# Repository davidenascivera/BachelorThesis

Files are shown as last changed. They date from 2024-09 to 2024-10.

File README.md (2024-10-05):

# Infrared Signal Devices for Aerial Obstacles

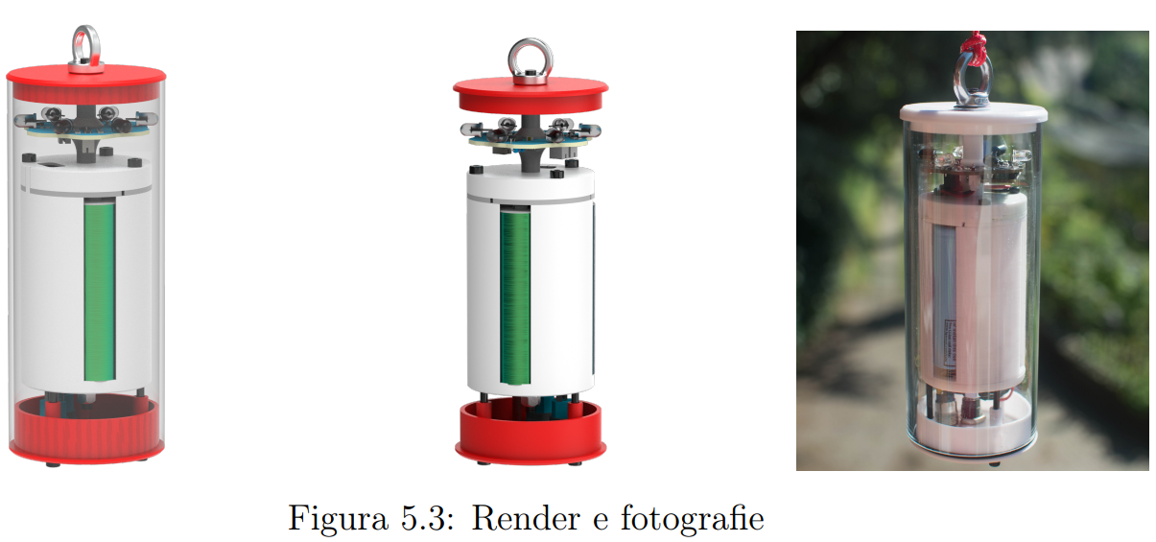
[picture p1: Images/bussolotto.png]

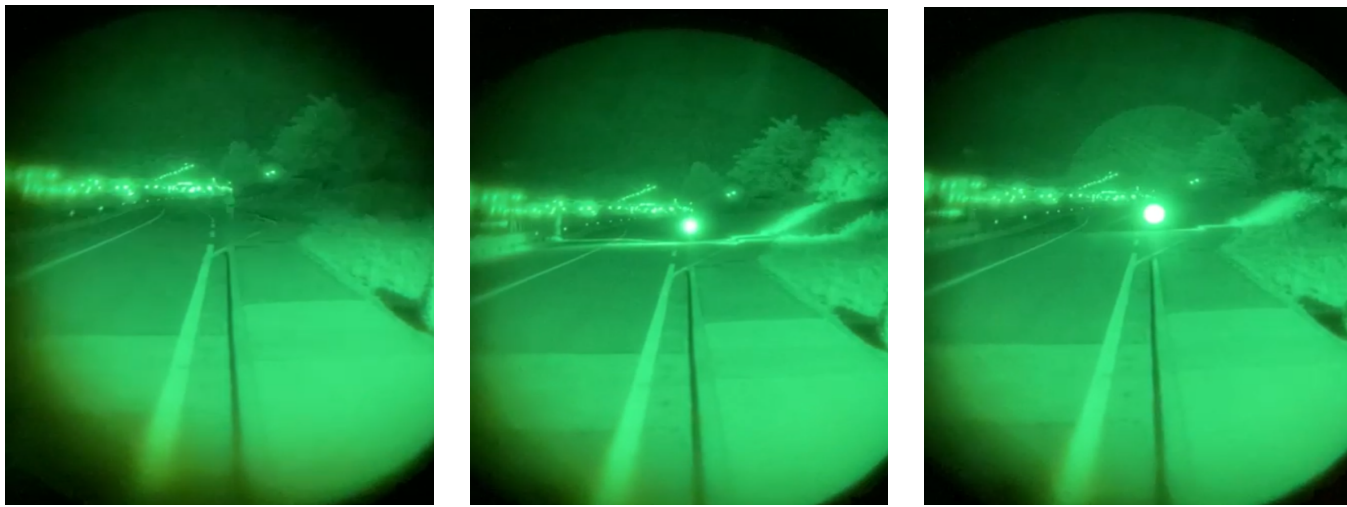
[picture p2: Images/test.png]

## Abstract

This project focuses on the design and development of **infrared signal devices** for aerial obstacle detection, aimed at improving the safety of temporary installations, such as **Highline** structures. Inspired by Swiss regulations for aerial navigation, these devices are designed to emit infrared light visible to night-vision equipment, particularly for helicopters used in rescue operations. The main goal is to offer an **open-source**, low-cost alternative to commercial infrared signal devices, which are often prohibitively expensive for nonprofit slackline communities.

## Project Overview

This repository contains the design files, schematics, and necessary documentation to build a fully operational infrared signal device, as developed in my Bachelor's thesis. The device has undergone several iterations, leading to the final version described below.

## Documentation

For more detailed information on the project, please refer to the following files:

- [Project Summary](Documentation/eng_summary.pdf)
- [Full_thesis](Documentation/eng_full_thesis)

Please note that the document was originally written in Italian and later translated for publication here.

### Features

- **Compact Design**: Comparable to a smartphone in size, the device is easy to transport and install.
- **Waterproof (IP67)**: The device is designed to operate in outdoor conditions, including rain.
- **Extended Battery Life**: With a single 18650 battery (3.2 Ah), the device can last up to 40 hours of continuous operation, or approximately 4 nights.
- **Cost-Effective**: The total cost per device is around €50, compared to €500 for commercial alternatives.
- **Customizable**: The device allows for various LED patterns and types, making it adaptable to different needs.

## Hardware Specifications

- **PCB Design**: The PCB was optimized for small-scale production, using **SMD components** to reduce size and improve performance.
- **LED Driver**: Infrared LEDs are powered by a dedicated current-driven LED driver, ensuring reliable operation and efficient power usage.
- **USB-C Charging**: The device includes a USB-C port for convenient recharging.
- **Visual Battery Indicator**: Upon powering on, the device shows the battery charge level via an LED, with 1 to 5 blinks indicating the charge status.

## Assembly Instructions

1. **Print the PCB Layout**: The design files for the PCB are included in the `/pcb_design` folder.
2. **Assemble Components**: Follow the schematic in the `/schematics` folder to solder the necessary components to the PCB.
3. **Install the Electronics in the Case**: The device case is designed for ease of access, with removable top and bottom covers for maintenance.
4. **Power On**: Once assembled, insert the battery, charge it via the USB-C port, and press the power button to activate the device.

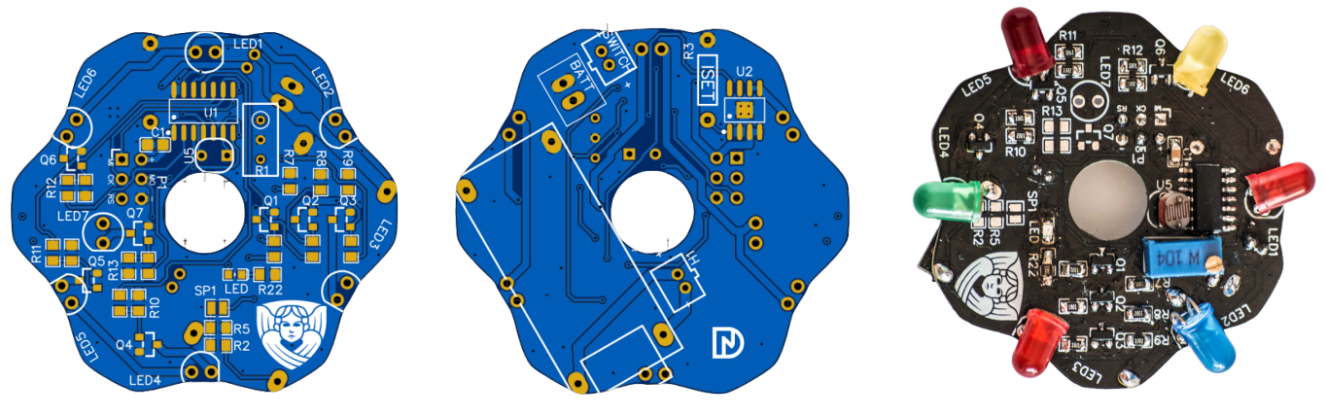
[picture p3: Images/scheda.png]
PCB of the system


## Testing and Validation

The device was tested in collaboration with the **Trento Helicopter Rescue Unit** to validate its performance. It was visible up to a distance of 500 meters under city light pollution and further in mountain environments, making it suitable for high-altitude slacklining installations.

## Future Improvements

- **Top-mounted Infrared LED**: Future versions could include an additional infrared LED visible from above.
- **Integrated Battery Management System (BMS)**: Incorporating the BMS directly into the PCB for a more seamless design.
- **Larger-Scale Production**: The current design is optimized for small-scale production, but further improvements can make it scalable for mass production.

## License

This project is open-source under the **MIT License**. Feel free to modify and adapt the design for your specific needs.
"""

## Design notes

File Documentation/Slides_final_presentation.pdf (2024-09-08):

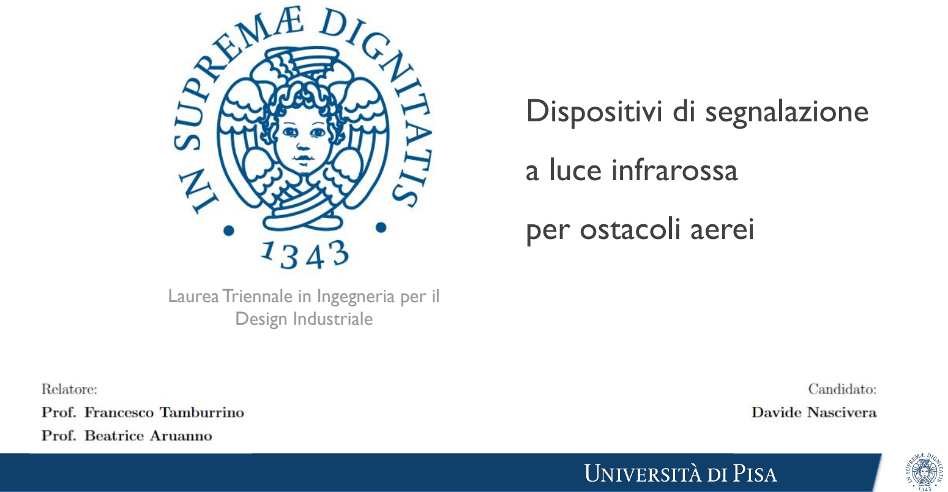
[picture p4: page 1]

## Dispositivi di segnalazione

## a luce infrarossa

## per ostacoli aerei

Laurea Triennale in Ingegneria per il Design Industriale

# Il problema

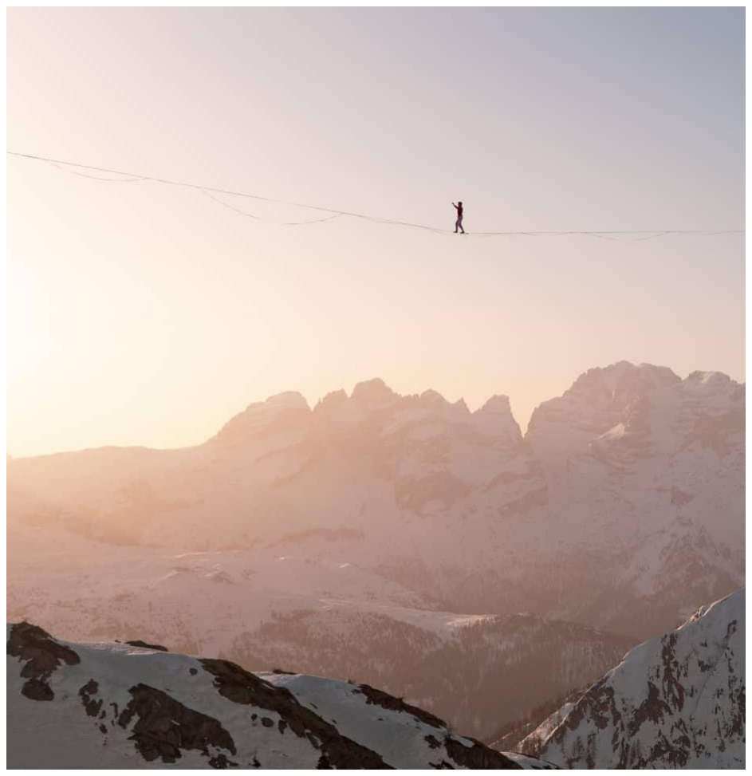
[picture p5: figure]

Lo Slacklining è lo sport, o disciplina, che consiste nel bilanciarsi e stare in equilibrio su una fettuccia tesa fra due punti di ancoraggio.

Fettucce sospese nel vuoto, quali Highline, rappresentano un rischio significativo per lo spazio aereo se non vengono gestite e controllate adeguatamente.
Pertanto durante le ore diurne vengono poste molteplici maniche a vento lungo un cordino parallelo alla linea, mentre di notte invece il problema persiste.

# Il problema

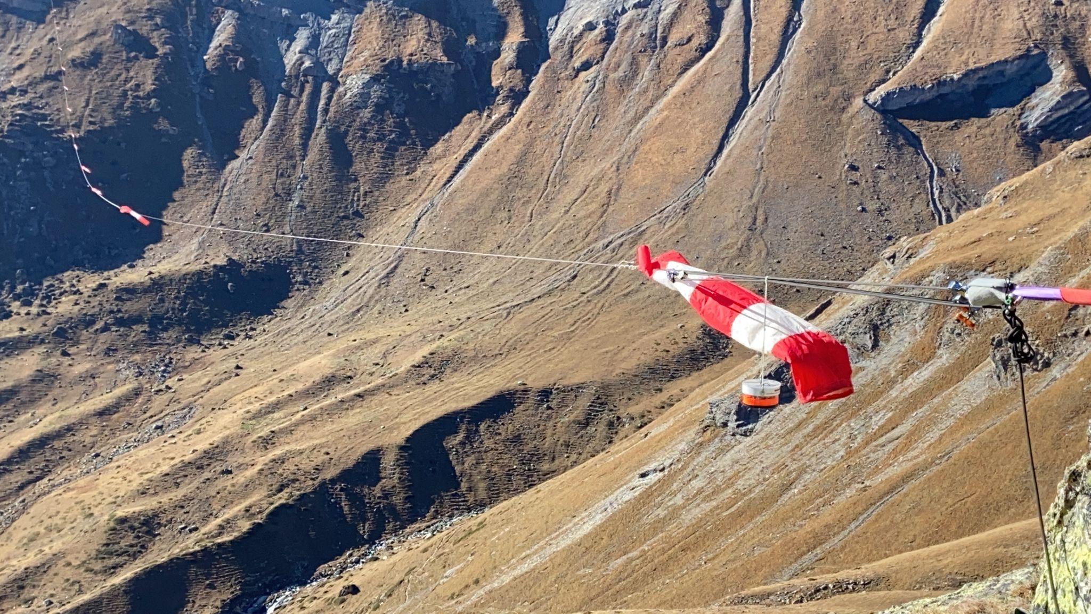
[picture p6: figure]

# Soluzione Svizzera:

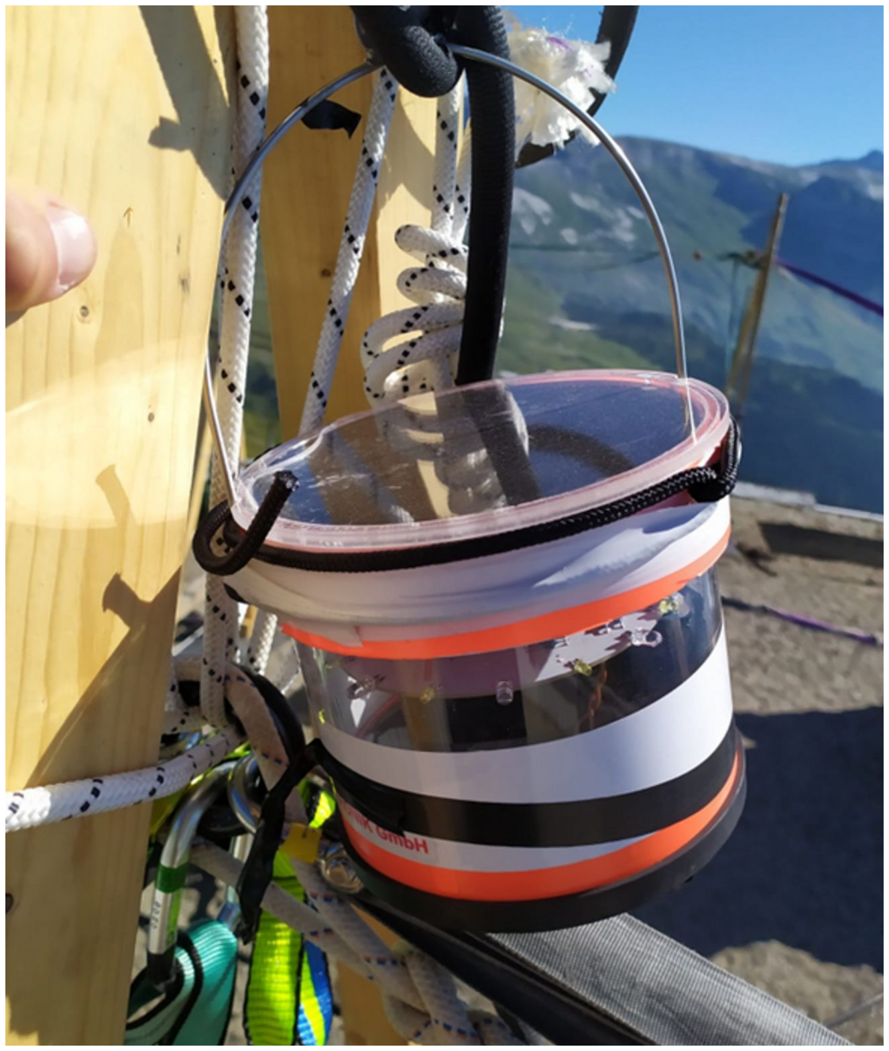
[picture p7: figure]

La Svizzera prevede già questo tipo d’installazione nella loro normativa locale.

I dispositivi di sicurezza usati dai cittadini costano 500 euro e il prezzo è proibitivo per associazioni no-profit dove non è obbligatorio l’utilizzo del dispositivo.

# Soluzione Open-Source:

L'obiettivo principale è lo sviluppo di un prodotto completo, accompagnato dalla pubblicazione di circuiti e file per la sua realizzazione, al fine di stabilire le basi per un sistema affidabile e conveniente.

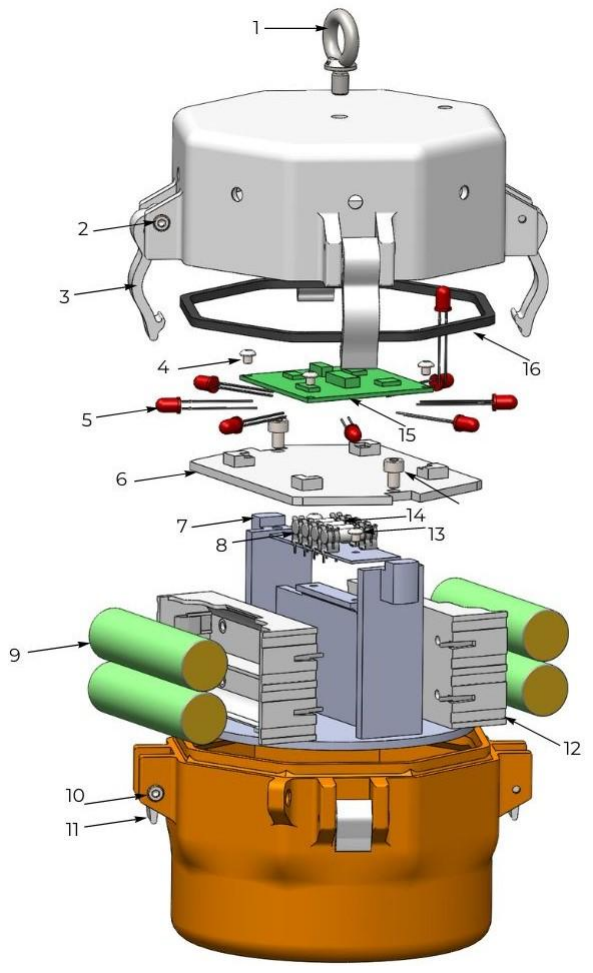
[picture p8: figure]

# Proof of concept

Sfruttando l’ispirazione derivante dal design dei dispositivi di segnalazione svizzeri, è stato possibile progettare e sviluppare un sistema di sicurezza basato su elementi già testati e affidabili, apportando però miglioramenti.

Il sistema si compone di una scocca esteriore impermeabile stampata in PETG che racchiude la parte elettronica e il pacco batterie al proprio interno.

8 LED infrarossi posizionati lungo i bordi dell'ottagono si attivano in modalità intermittente per fornire la segnalazione necessaria

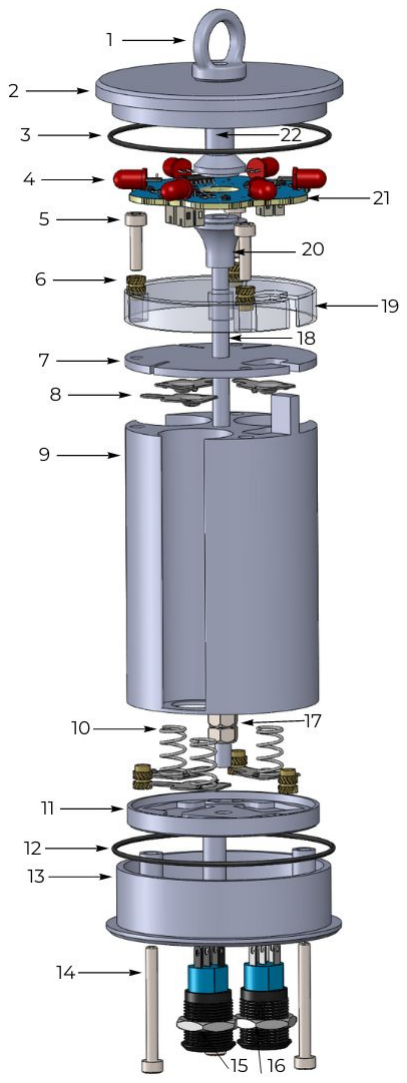
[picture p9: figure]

# Proof of work

La quarta e ultima versione del dispositivo risulta essere più elegante e avanzata a livello tecnico e meccanico.

Il risultato è un dispositivo con dimensioni paragonabili a quelle di uno smartphone, impermeabile e con un'elettronica efficiente che permette la messa in opera del dispositivo per 4 giorni per ogni batteria inserita.

Per ricaricare le batterie del dispositivo è sufficiente collegare la dedicata USB-C. Inoltre non è più necessario aprire il dispositivo per attivarlo, disponendo del pulsante d’accensione esterno.

Al momento dell'accensione, il dispositivo indica la percentuale di carica mediante il lampeggio di un LED integrato da 1 a 5 volte.

# Confronto fra dispositivi

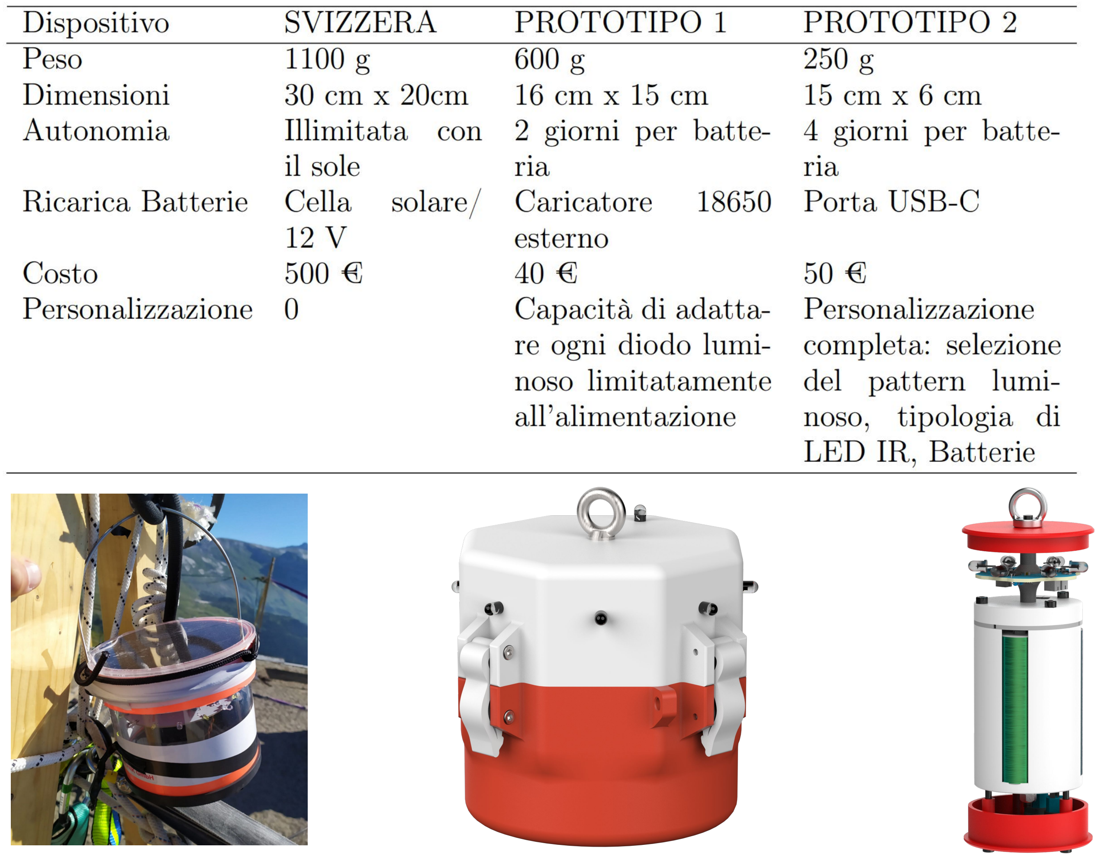
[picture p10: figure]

# Verifica del dispositivo

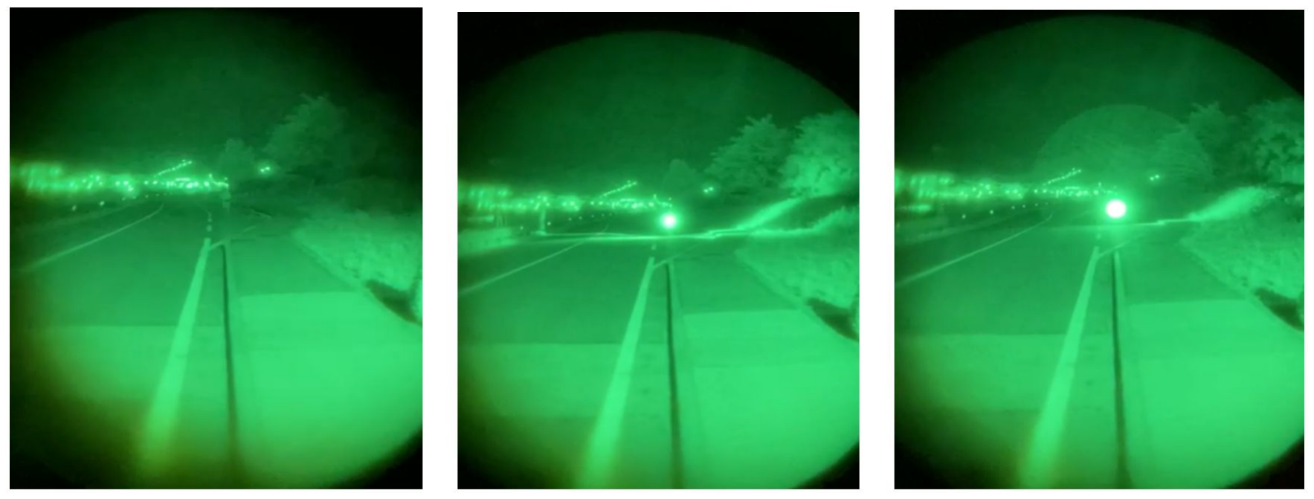
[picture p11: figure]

La validazione operativa è stata eseguita in collaborazione con il nucleo elisoccorso di Trento.
Il dispositivo risulta essere notevolmente visibile anche a una distanza di 500 m con l’inquinamento luminoso della città in prossimità dell’aeroporto.

In base alle numerose prove di laboratorio, il dispositivo è classificato con un grado di impermeabilità IP67 e offre la batteria offre un'autonomia di circa 12 giorni.

# Future implementazioni

Nonostante il progetto sia un prodotto completo e utilizzabile, esistono alcuni punti che potrebbero essere ampliati e perfezionati:

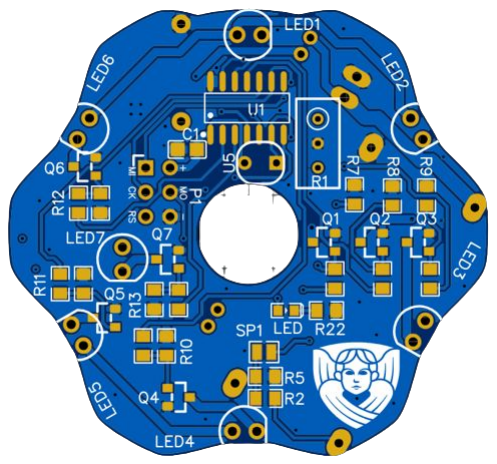
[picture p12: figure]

- Certificare il funzionamento del dispositivo, sia a livello elettronico che ottico da laboratori specifici.
- Implementazione del LED infrarossi superiore
- Inclusione del modulo di ricarica e del BMS all’interno della scheda elettronica

# Conclusioni

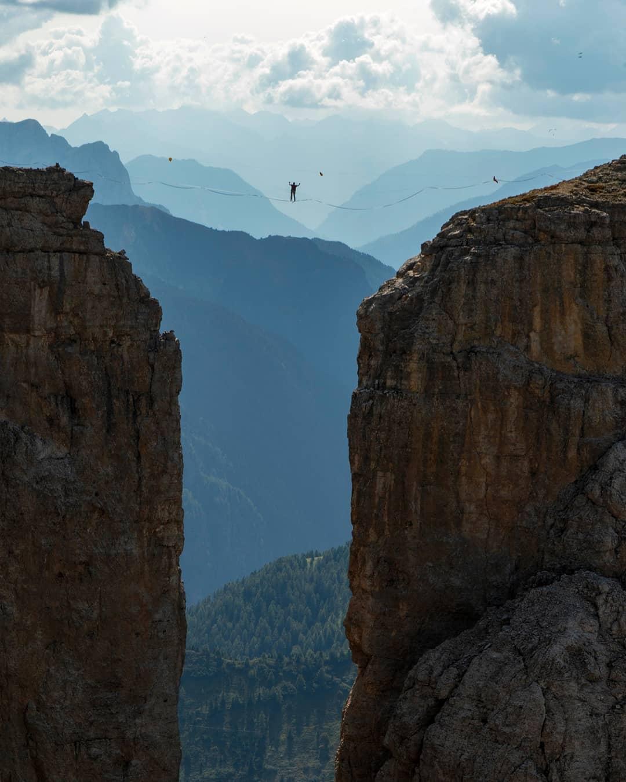
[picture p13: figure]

In conclusione si può affermare che è stato sviluppato un dispositivo in grado di affrontare con successo le sfide specifiche, caratterizzato da un design leggero, compatto e altamente portatile.

Il suo prezzo accessibile ed estremamente conveniente risulta particolarmente adatto per le comunità no-profit interessate alla slackline.

# Grazie per l’attenzione

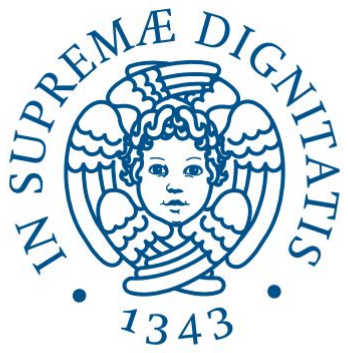
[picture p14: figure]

# Domande:

# Montaggio di un’Highline

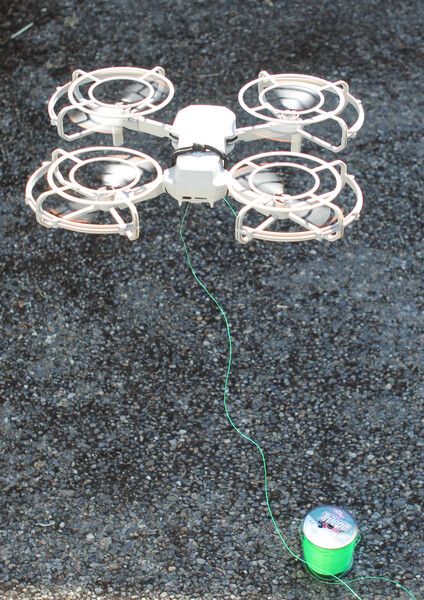
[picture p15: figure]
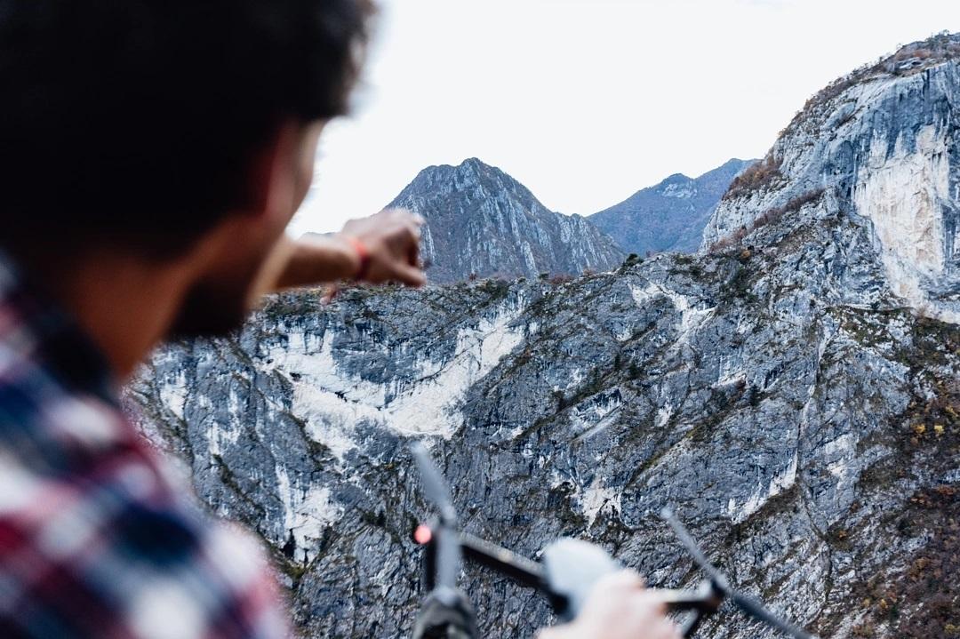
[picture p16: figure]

1. Ricerca della location. | 2. Utilizzo del drone per
| passaggio della bava.

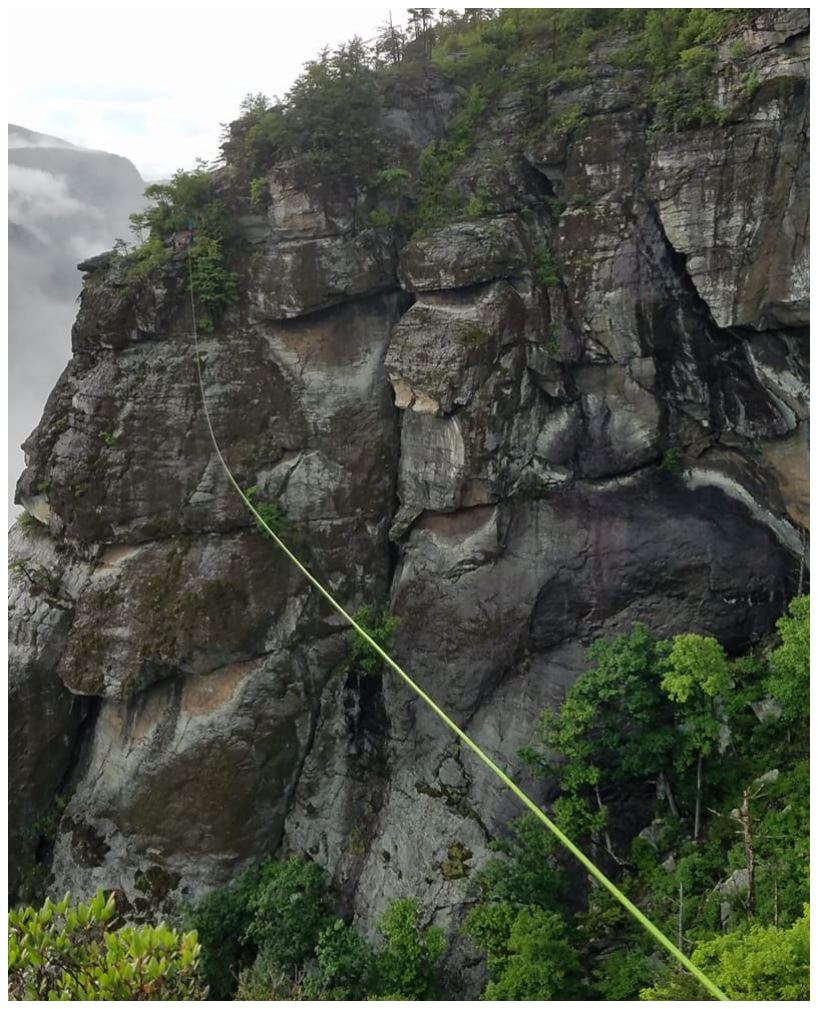
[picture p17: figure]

3. Passaggio della
tagline con la bava

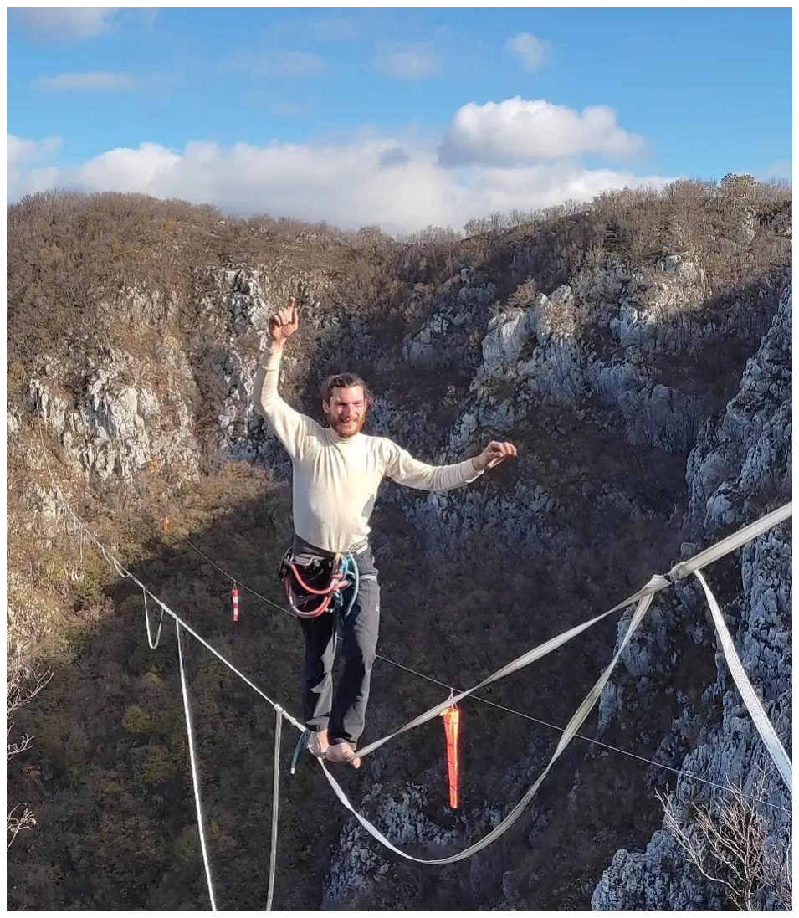
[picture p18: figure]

4. Passaggio della
slackline

# Componenti di un’installazione

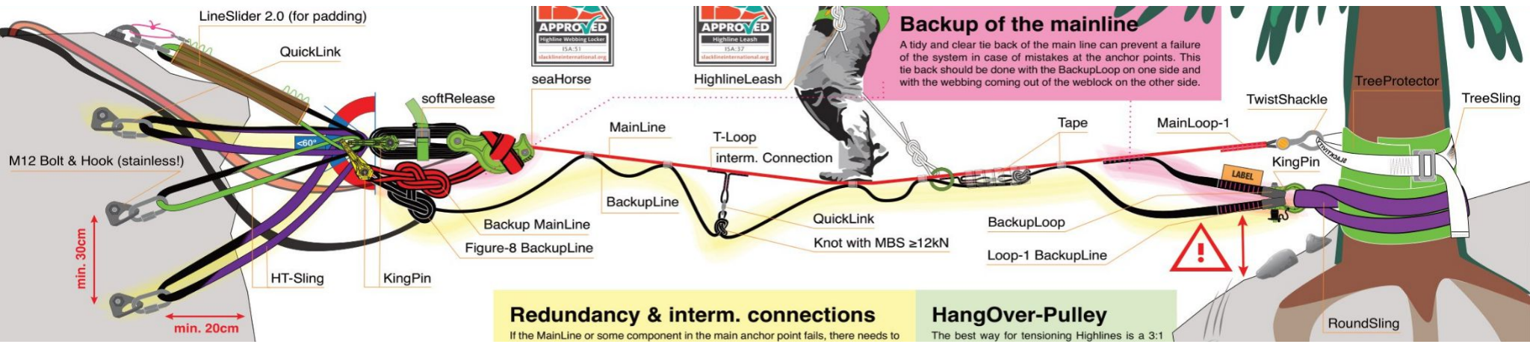
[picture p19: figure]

# Manovra di risalita

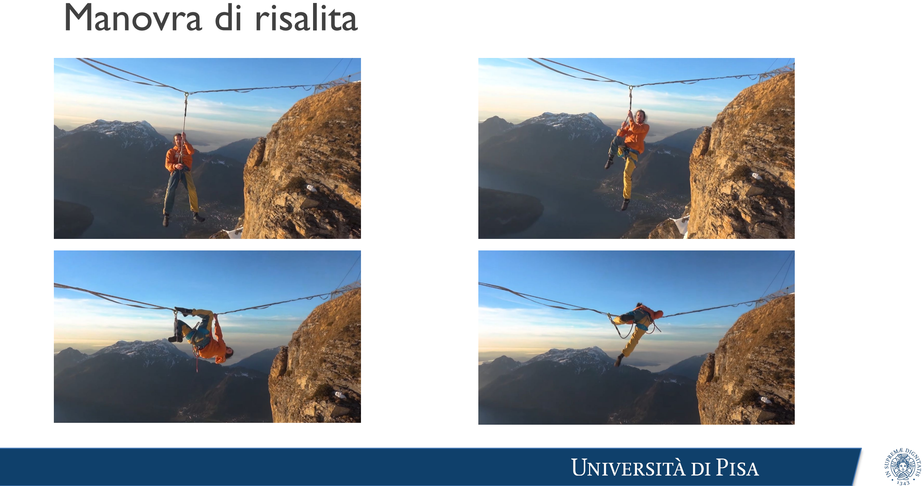
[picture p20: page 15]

# Nuovo compentitor: Lira

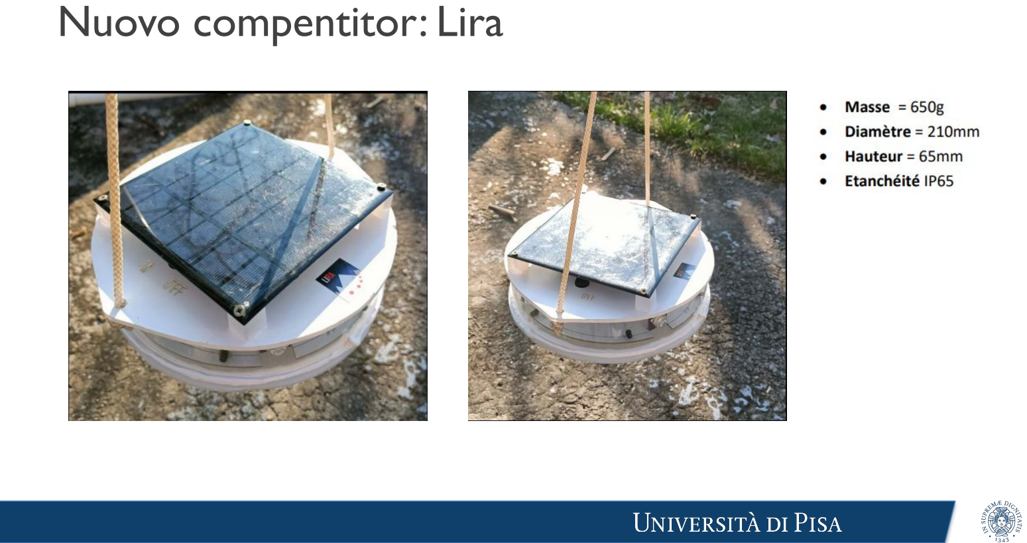
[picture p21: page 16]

# Programmazione dispositivo

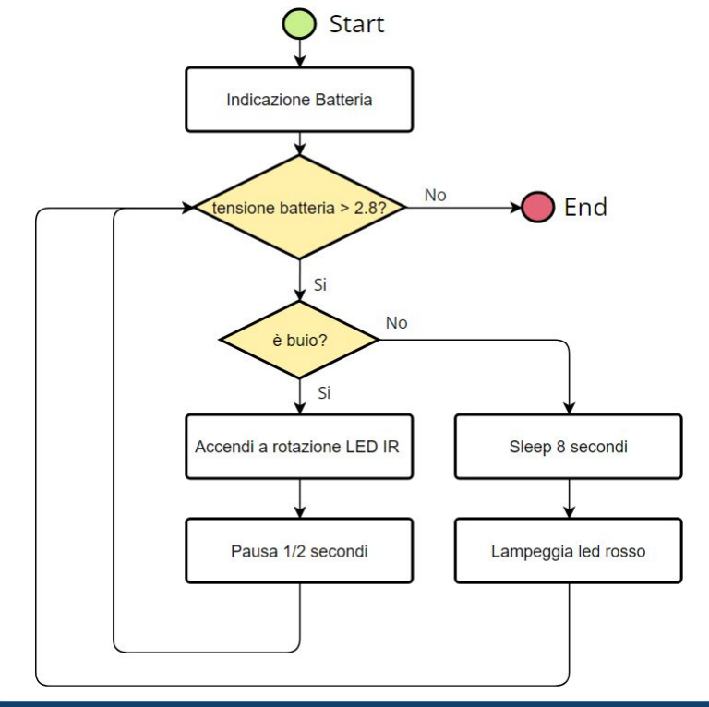
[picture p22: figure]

# Permeabilità ottica PMMA

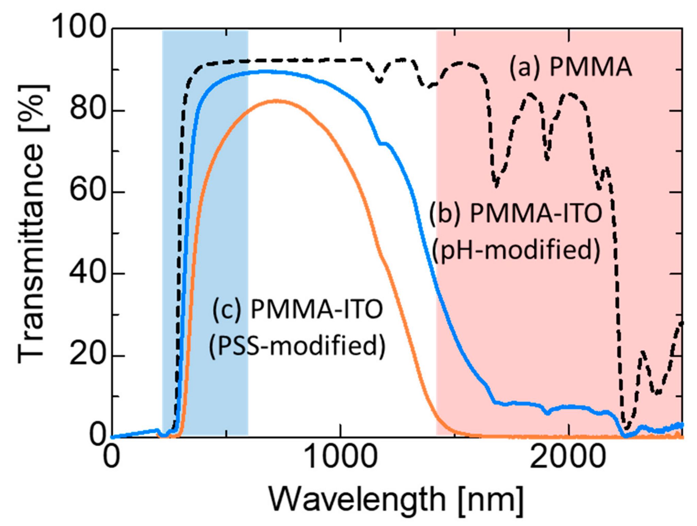
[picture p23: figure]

Fig. 5. Transmission spectra of PMMA, PET, CL400 substrates and Su8 waveguide layers.

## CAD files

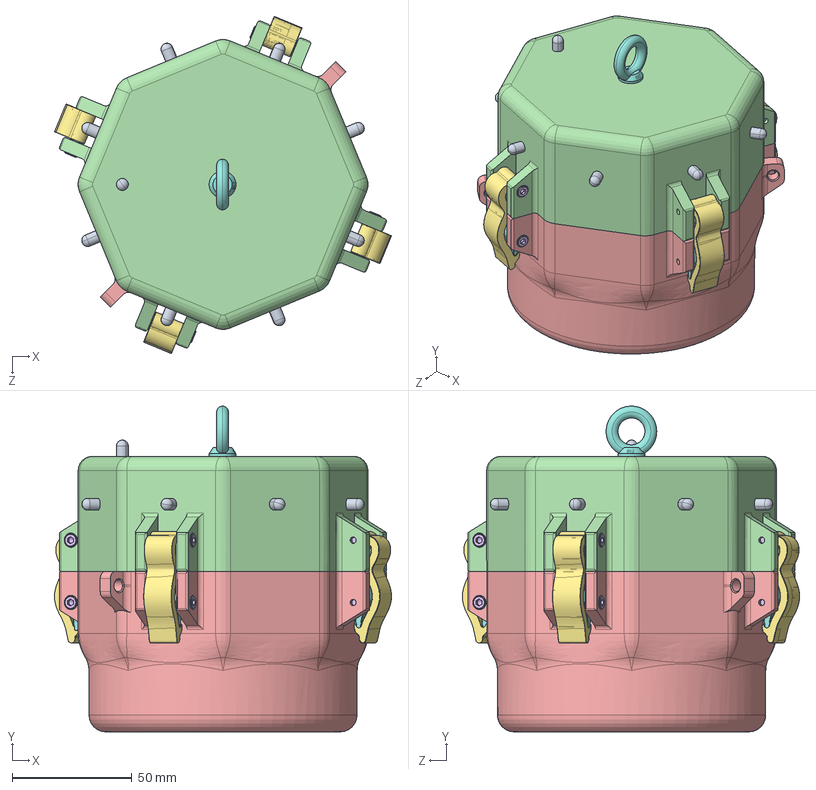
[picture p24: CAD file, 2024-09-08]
CAD/assieme_vecchia_versione/Assieme1.SLDASM
140.6 x 136.0 x 140.7 mm
completo-Estrusione-Estrusione57
completo-Estrusione-Estrusione61
completo-portabatteria
completo-sopra
completo-sotto
socket head cap screw_am x 10
arm x 4
cam x 4
5mm LED (1) x 9
18650m_2.STEP x 2
18650s_По умолчанию.STEP x 8
NCR 18650B x 4
socket button head cap screw_am x 6
completo-Estrusione-Estrusione64
fuse-4skt_p5_l21_w7_h8-2 x 4
CHI42
completo-Estrusione-Estrusione661

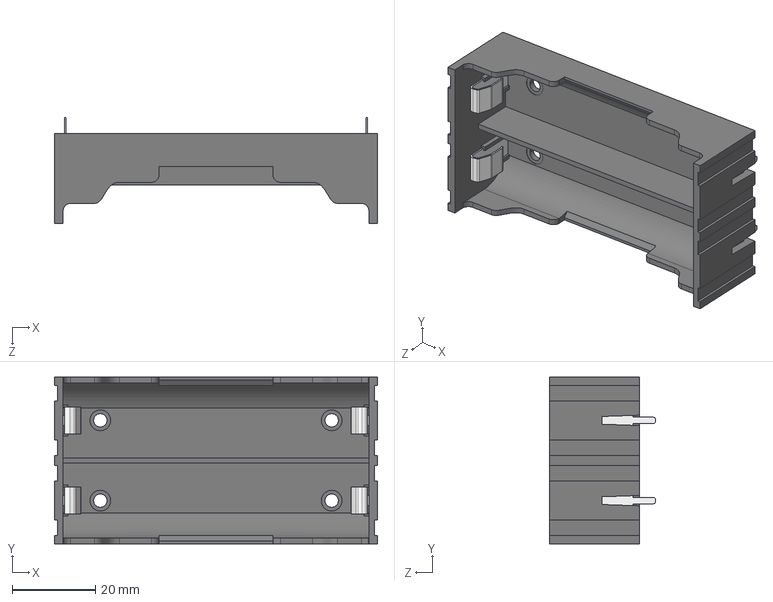
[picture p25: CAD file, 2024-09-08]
CAD/assieme_vecchia_versione/User Library-18650 Full.STEP
77.6 x 40.1 x 25.5 mm
18650m_2
18650s_По умолчанию x 4

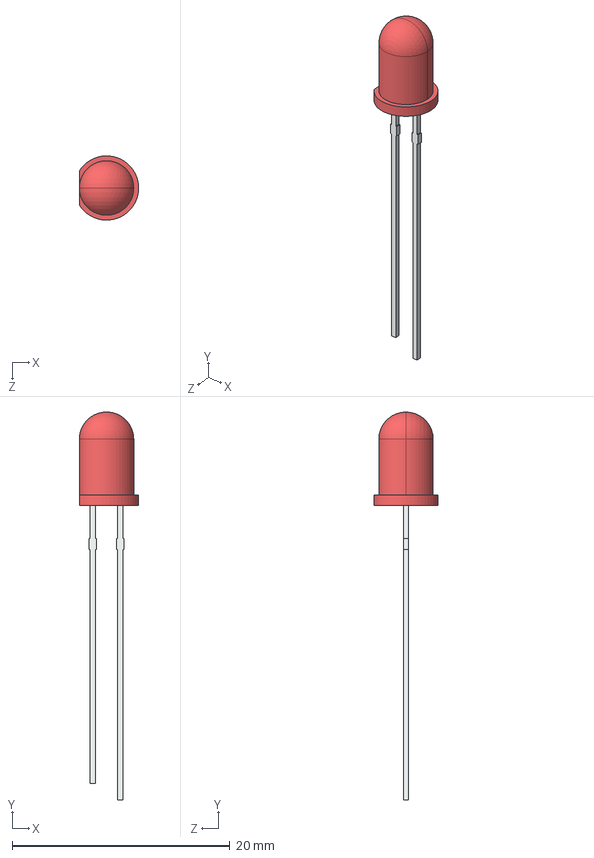
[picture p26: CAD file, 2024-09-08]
CAD/Assieme/5mm LED (1).STEP
5.45 x 35.6 x 5.90 mm

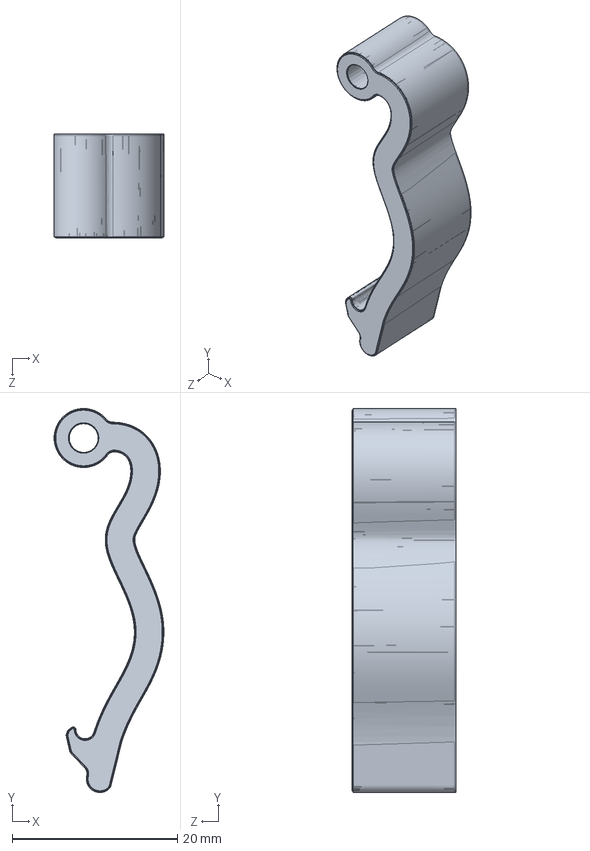
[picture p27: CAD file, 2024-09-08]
CAD/assieme_vecchia_versione/arm.SLDPRT
13.3 x 46.5 x 12.6 mm

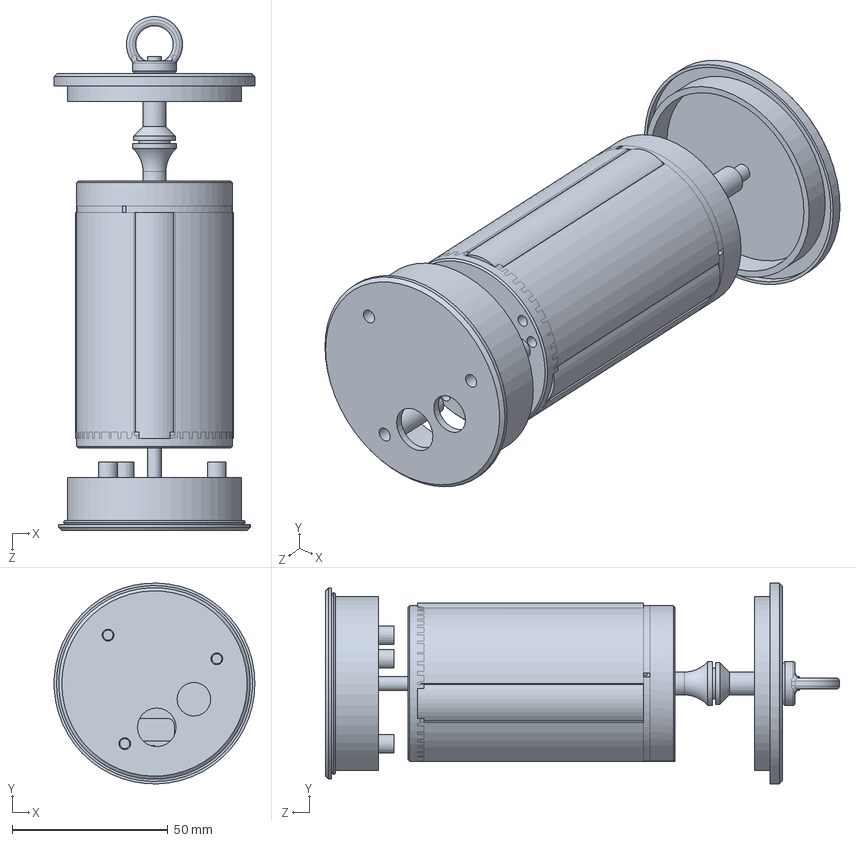
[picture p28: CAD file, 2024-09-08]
CAD/versioneM4.SLDPRT
64.4 x 64.4 x 164.8 mm

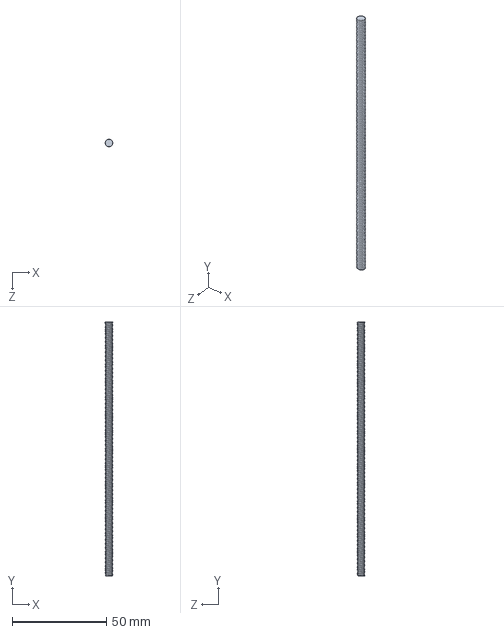
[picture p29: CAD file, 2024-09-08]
CAD/Assieme/BarraFilettat.SLDPRT
4.00 x 134.7 x 4.00 mm

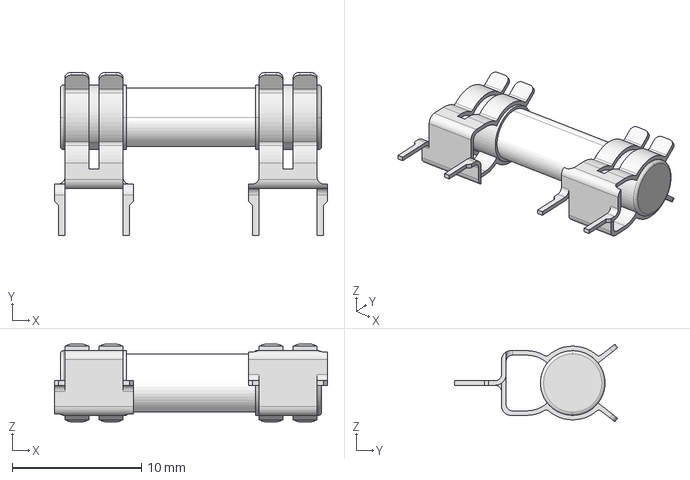
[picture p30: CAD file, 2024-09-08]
CAD/assieme_vecchia_versione/fuse-4skt_p5_l21_w7_h8-2.stp
21.1 x 12.6 x 6.00 mm

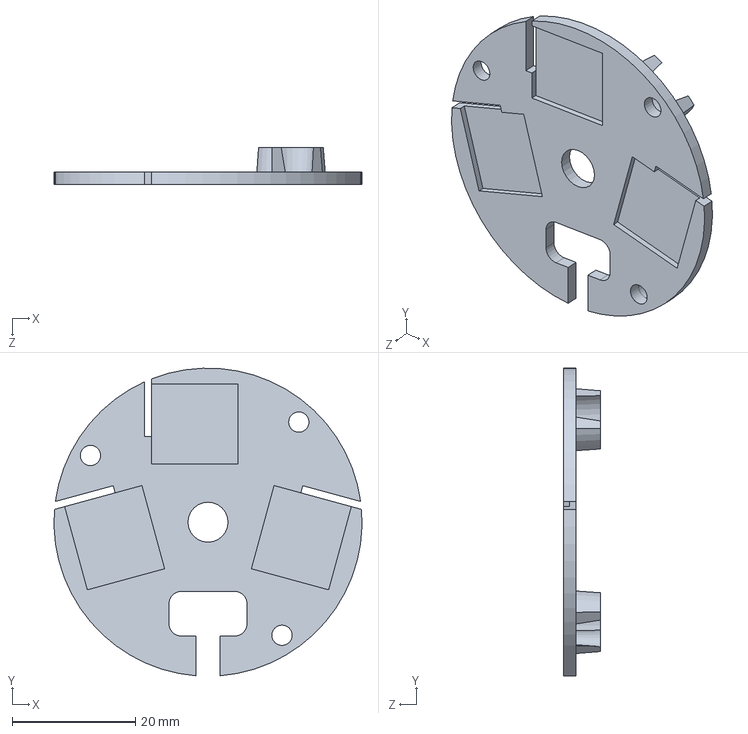
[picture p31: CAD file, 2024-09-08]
CAD/Assieme/versioneM4-Estrusione-Estrusione9.SLDPRT
50.0 x 49.9 x 6.00 mm

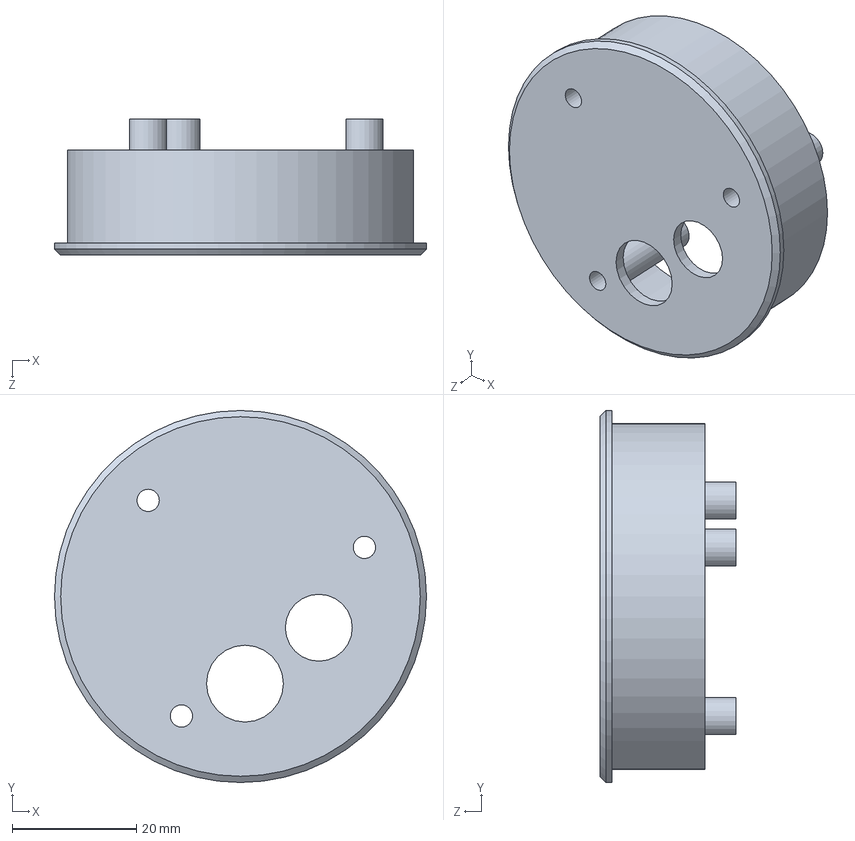
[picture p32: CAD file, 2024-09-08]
CAD/Assieme/versioneM4-Estrusione-Estrusione15.SLDPRT
60.0 x 60.0 x 22.0 mm

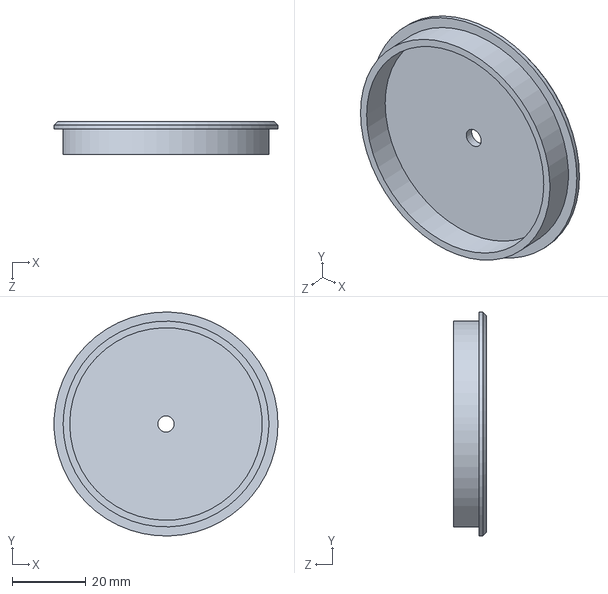
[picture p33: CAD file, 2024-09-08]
CAD/Assieme/versioneM4-Estrusione-Estrusione18.SLDPRT
60.8 x 60.8 x 9.00 mm

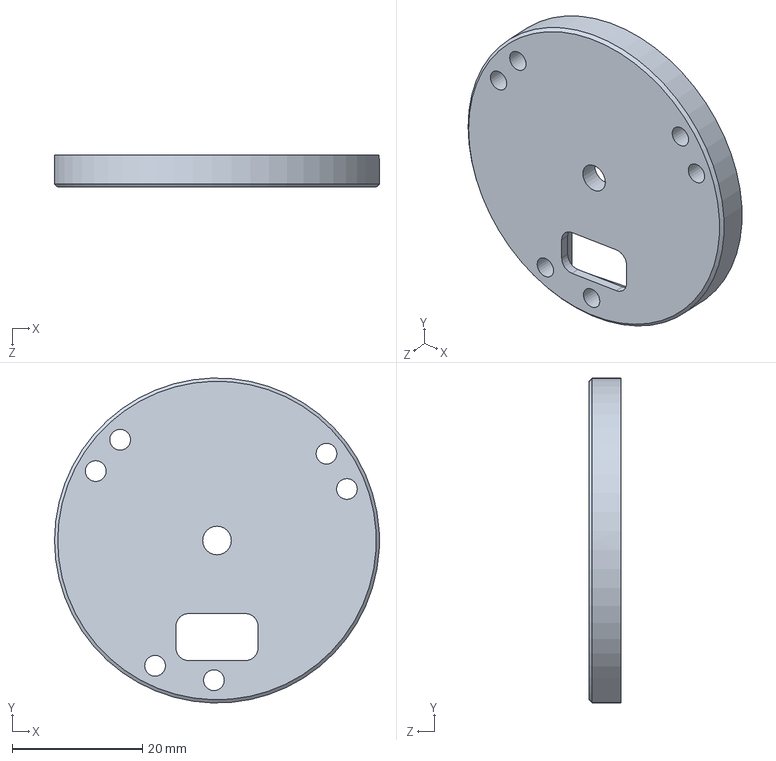
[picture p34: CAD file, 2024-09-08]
CAD/Assieme/versioneM4-Estrusione-Estrusione5.SLDPRT
50.0 x 50.0 x 5.00 mm

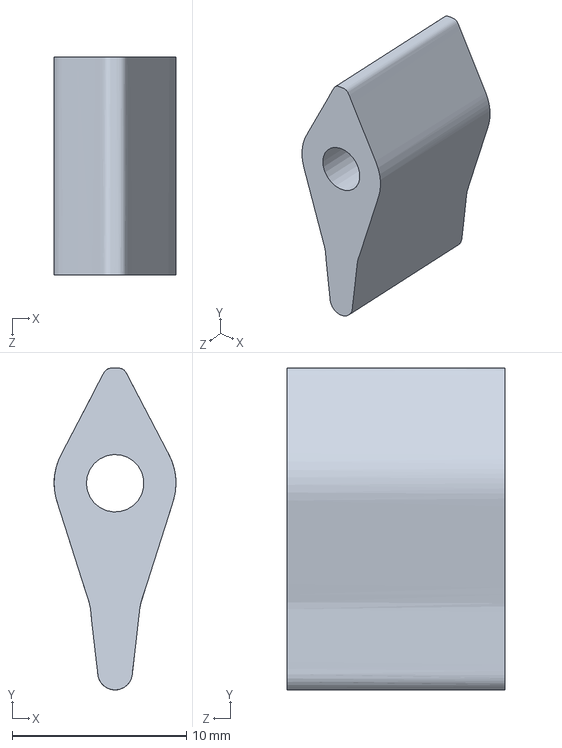
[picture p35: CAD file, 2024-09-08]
CAD/assieme_vecchia_versione/cam.SLDPRT
7.00 x 18.5 x 12.5 mm

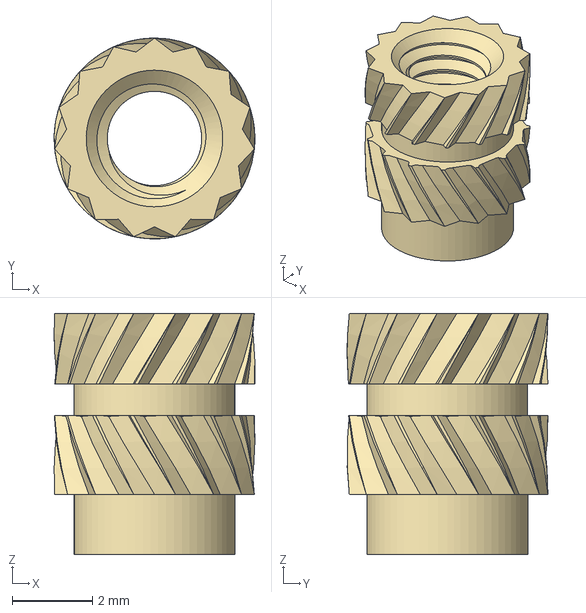
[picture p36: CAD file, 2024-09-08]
CAD/Assieme/Insert M3 D5 L5mm.stp
5.00 x 5.00 x 6.00 mm

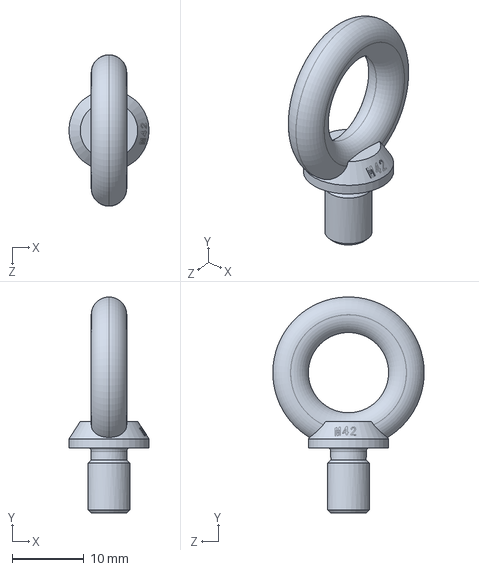
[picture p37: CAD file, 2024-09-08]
CAD/assieme_vecchia_versione/CHI42.SLDPRT
11.2 x 30.2 x 21.1 mm

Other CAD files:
CAD/Assieme/versioneM4-Estrusione-Estrusione4.SLDPRT
CAD/assieme_vecchia_versione/completo-Estrusione-Estrusione57.SLDPRT
CAD/Assieme/versioneM4-Estrusione-Estrusione28.SLDPRT
CAD/assieme_vecchia_versione/completo-portabatteria.SLDPRT
CAD/Assieme/16mm Metal Pushbutton.step
CAD/Assieme/5mm LED (1).SLDPRT
CAD/Assieme/BarraFilettataSemplificata.SLDPRT
CAD/Assieme/Battery spring plates.step
CAD/Assieme/Insert M3 D5 L5mm.SLDPRT
CAD/Assieme/NCR 18650B.SLDPRT
CAD/Assieme/NCR 18650B.STEP
CAD/Assieme/User Library-JST B2B-PH-K-S.sldprt
CAD/Assieme/plate.SLDPRT
CAD/Assieme/pulsante.SLDPRT
CAD/Assieme/spring.SLDPRT
CAD/Assieme/usbC.SLDPRT
CAD/Assieme/versioneM4-Estrusione-Estrusione10.SLDPRT
CAD/Assieme/versioneM4-Estrusione-Estrusione14.SLDPRT
CAD/Assieme/versioneM4-Estrusione-Estrusione21.SLDPRT
CAD/Assieme/versioneM4-Estrusione-Estrusione22.SLDPRT
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

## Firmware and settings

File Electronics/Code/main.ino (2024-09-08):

#define temp 100

#include "tinysnore.h"
class SystemStatus {
  
  public:
    
    uint8_t pin_batt;

    SystemStatus(uint8_t apin_batt);
    SystemStatus();
    int getVCC();
    int8_t getTemperatureInternal();    
};


SystemStatus::SystemStatus(uint8_t apin_batt) : pin_batt(apin_batt) {

}

SystemStatus::SystemStatus() : pin_batt(255) {

}


int SystemStatus::getVCC() {
  
  ADMUX = _BV(MUX5) | _BV(MUX0); 
  delay(2); 
  ADCSRA |= _BV(ADSC); 
  while (bit_is_set(ADCSRA, ADSC));
  uint8_t low = ADCL;
  unsigned int val = (ADCH << 8) | low;
  ADCSRA |= _BV(ADSC);
  while (bit_is_set(ADCSRA, ADSC));
  low = ADCL;
  val = (ADCH << 8) | low;
  
  return ((long)1024 * 1100) / val;  
}


int8_t SystemStatus::getTemperatureInternal() {

  ADMUX = (1<<REFS0) | (1<<REFS1) | (1<<MUX3); 
  delay(2); 
  ADCSRA |= bit(ADSC);
  while (ADCSRA & bit(ADSC));
  uint8_t low  = ADCL;
  uint8_t high = ADCH;
  ADCSRA |= bit(ADSC);
  while (ADCSRA & bit(ADSC));
  low  = ADCL;
  high = ADCH;
  int a = (high << 8) | low;
  return a - 272; 
}



int tensione;

void setup()// Initiate pin 2 as an output
{
  int carica;
  DDRA = 0b01101111;
  DDRB = 0b00000111; 
  
  tensione =SystemStatus().getVCC();
  if(tensione>4000){
    carica=5;
  }
  else if (tensione>3900){
    carica=4;
  }
  else if (tensione>3800){
    carica=3;
  }  
  else if (tensione>=3600){
    carica=2;
  }  
  else if (tensione>3450){
    carica=1;
  }  
  else{
    carica=0;
  }
  for (int i = 0; i < carica; i++){
    PORTA = 0b00000000;//ledStatus
    delay(200);
    PORTA = 0b01000000;//ledStatus
    delay(200);
  }
  delay(100);
}  

// the loop function runs over and over again forever
void loop() 
{

      if((analogRead(7)<800)&&(tensione>2800))
      {
        for(int i=0; i<2; i++)
        {
            PORTB = 0b00000100;
            PORTA = 0b00000001; //led1
            delay(temp);
            PORTA = 0b00000010;//led2
            delay(temp);
            PORTA = 0b00100000;//led3
            delay(temp);
            PORTA = 0b00000100;//led4
            delay(temp);
            PORTA = 0b00001000;//led4
            delay(temp);
            PORTA = 0b00000000;//led5
            PORTB = 0b00000101;//led5
            delay(temp);
            PORTB = 0b00000100;//led6
            delay(temp);
            PORTB = 0b00000000;//led6
        }
        PORTB = 0b00000000;
        PORTA = 0b01000000;
        delay(100);
        PORTA = 0b00000000;//ledStatus
        delay(100);
        PORTA = 0b01000000;//ledStatus
        delay(100);
        PORTA = 0b00000000;//ledStatus
        delay(100);
    }
    else
    {
      delay(3000);
      tensione =SystemStatus().getVCC();
      PORTA = 0b01000000;//ledStatus
      delay(100);
      PORTA = 0b00000000;//ledStatus
      delay(100);
    }
}
